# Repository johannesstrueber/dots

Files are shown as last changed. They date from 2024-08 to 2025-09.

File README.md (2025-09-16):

## Overview

DOTS is a compact, 6-channel Eurorack module designed for generating triggers and gates. This open hardware project allows you to build the module yourself, with instructions and resources provided. Please visit the [website](http://www.d-o-t-s.net) for more info.
<p align="left">
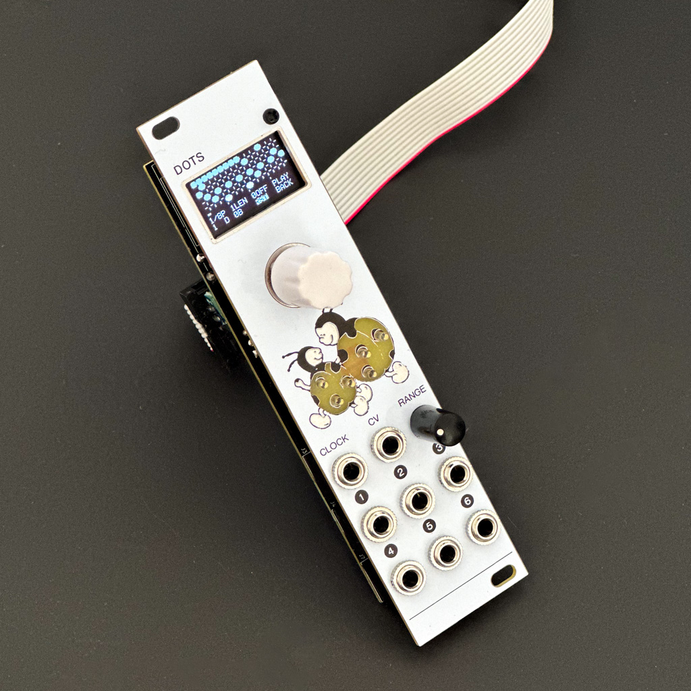
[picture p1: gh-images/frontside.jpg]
frontside
  
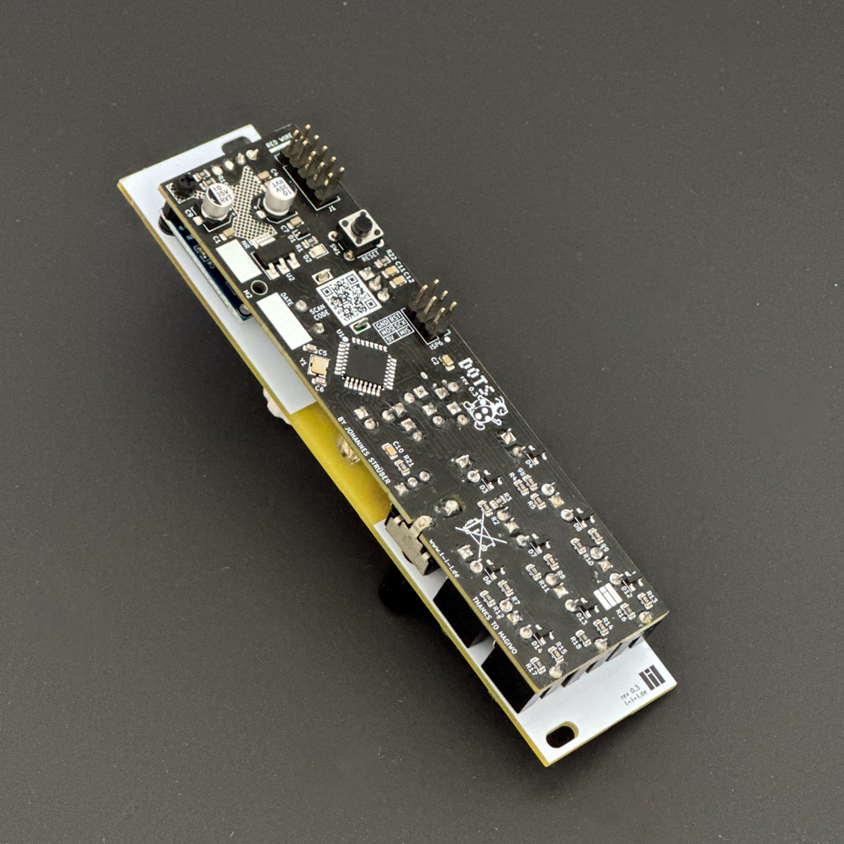
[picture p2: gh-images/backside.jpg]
backside
  
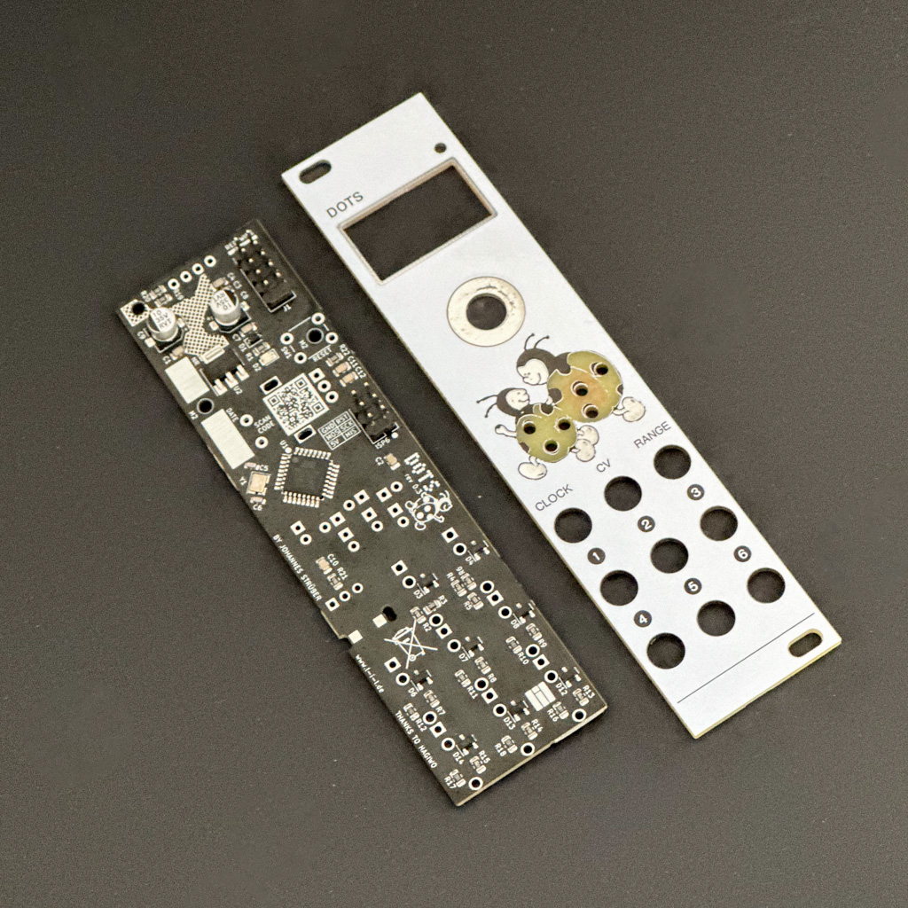
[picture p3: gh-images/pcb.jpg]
pcb
  
</p>

## Features

Watch a quick demo video [here](https://www.youtube.com/watch?v=c7fAQ9qpfXI).

- **6-Channel Trigger/Gate**: Generate triggers and gates for your modular system.
- **Compact Size**: Only 6hp wide, making it a handy addition to your setup.
- **Sync Capabilities**: Includes a clock and reset input, allowing it to function as a master or slave.
- **Visual Feedback**: Equipped with a screen and an UI.
- **Multiple Programs**: The firmware features multiple programs for different trigger/gate patterns and functionalities.

## Instructions

Check the [website](http://www.d-o-t-s.net) for detailed instructions on how to order, build and flash the module.

## Resources

- **[Website](http://www.d-o-t-s.net)**: Main website for the project.
- **[Order Guide](http://www.d-o-t-s.net/order)**: Order your DOTS PCB and front panel.
- **[Build Guide](http://www.d-o-t-s.net/build)**: Detailed instructions and an interactive Bill of Materials.
- **[Installation Guide](http://www.d-o-t-s.net/installation)**: Instructions for flashing the firmware to your DOTS module.
- **[Manual](http://www.d-o-t-s.net/manual)**: Comprehensive manual for using the module.
- **[Firmware on GitHub](https://www.github.com/releases)**: Download the latest firmware for the module.
- **[Modulargrid.net](https://modulargrid.net/e/other-unknown-dots)**: Module page on Modulargrid.net.

## Technical Specifications

- **Width**: 6HP
- **Depth**: ~30mm
- **Clock Input**: 0-5V triggers/gates
- **Reset Input**: 0-5V triggers/gates  
- **Outputs**: 6x 0-5V triggers/gates
- **Display**: 128x64 OLED
- **Microcontroller**: ATmega328P
- **Memory**: EEPROM storage for patterns and settings

### Modes

- **Step Sequencer**: Classic 16-step pattern programming with 8 pattern banks and visual step editing
- **Euclidean Sequencer**: Generate complex polyrhythmic patterns using Euclidean algorithms with individual channel control
- **Clock Divider**: Individual channel dividers (÷1 to ÷16) for creating polyrhythmic sequences and musical divisions
- **Random Trigger**: Probability-based trigger generation with adjustable chance per channel
- **Configuration Menu**: Comprehensive settings for BPM, clock modes, output types, and more

## Development

### Building from Source

1. **Prerequisites**: Install [PlatformIO](https://platformio.org) and [Git](https://git-scm.com)
2. **Clone**: `git clone https://github.com/johannesstrueber/dots.git`
3. **Build**: `platformio run`
4. **Flash**: Use `./flash_sequencer.sh` for automated flashing with default patterns

### Editing EEPROM Configuration

eeprom_config.cpp contains default settings and pattern configurations. Modify this file to customize the initial state of your module.

## Repository Structure

- **/code/include**: Header files and module implementations
- **/code/src/main.cpp**: Main firmware entry point
- **/code/src/eeprom_config.cpp**: Default settings and pattern configuration
- **/kicad_frontpanel**: Front panel PCB design files ([KiCad](https://kicad.org))
- **/kicad_main**: Main PCB design files ([KiCad](https://kicad.org))
- **diagram.json**: Hardware simulation ([WOKWI](https://wokwi.com))
- **platformio.ini**: Build configuration ([PlatformIO](https://platformio.org))
- **flash_module.sh**: Automated flashing script with EEPROM configuration

## Disclaimer

This is a personal project and not a commercial product. The creator is not liable for any damage caused by the module. Use at your own risk. The project is licensed under a [Creative Commons Attribution-NonCommercial-ShareAlike 4.0 International License][cc-by-nc-sa].

[][cc-by-nc-sa]

If you have any questions, feel free to contact the creator. This is a hobby project, and the creator is a web developer, not a professional hardware embedded systems builder; some hardware design or code decisions may seem unconventional.

Special thanks to HAGIWO for providing foundational knowledge.

Happy Building!

[cc-by-nc-sa]: http://creativecommons.org/licenses/by-nc-sa/4.0/
[cc-by-nc-sa-shield]: https://img.shields.io/badge/License-CC%20BY--NC--SA%204.0-lightgrey.svg

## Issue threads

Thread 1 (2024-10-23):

Feature request: Quick change in SEQ

Elko-cmd, 2024-10-23:
# Useability

## Hold and Twist
I would like to suggest registering a button hold of the encoder.
This could be used in the seq-program to invert the state of the individual Steps.
It would allow for a quicker change of patterns.
## Double press
A short double press of the Encoder could be used for quick access Play/Pause functionality

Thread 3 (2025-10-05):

PCB slot for RANGE potentiometer needs adjustment

johannesstrueber, 2025-10-05:
A user reported that the RANGE potentiometer did not sit straight because the slots in the PCB for the potentiometer legs are about 1mm too high. They resolved the issue by filing the PCB to extend the slot lower, after ensuring no PCB traces would be damaged.

**Suggested improvement:**
- Adjust the slot position for the RANGE potentiometer in the PCB design files so that it aligns properly and does not require manual modification by the user.
- Verify that moving the slot lower will not interfere with existing PCB traces.

**Reference:**
User feedback via email: "The RANGE potentiometer didn't sit straight. The slots in the PCB for the potentiometer legs are about 1mm too high. So, I filed the PCB to extend the slot lower. (I first checked that I wasn't damaging any PCB traces.)"

This will improve the assembly experience and reduce manual intervention.

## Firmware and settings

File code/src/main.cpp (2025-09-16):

#include "constants/ConstantsProgMem.h"
#include "utilities/Bit.h"
#include "utilities/SplashScreen.h"
#include "utilities/Startup.h"

#include <Adafruit_GFX.h>
#include <Adafruit_SSD1306.h>
#include <Arduino.h>
#include <EEPROM.h>
#include <Encoder.h>
#include <Wire.h>
#include <avr/pgmspace.h>

const uint8_t outputPins[] = {5, 6, 7, 8, 9, 10};
int8_t numChannels = 6;

bool clockIn = false;
bool oldClockIn = false;
bool resetIn = false;
bool oldResetIn = false;

Encoder Enc(3, 2);
int8_t enc = 0;
bool encLock = false;

const uint8_t rows = 6;
const uint8_t cols = 16;
const uint8_t pages = 8;
const uint8_t barLength = 4;

const uint8_t seqMatrixSize = pages * rows * cols / 8;
byte seqMatrix[seqMatrixSize];

uint8_t randomChannelValues[6] = {0, 0, 0, 0, 0, 0};

uint8_t seqCurrentPage = 1;
uint8_t seqCurrentLength = 1;
uint8_t seqCurrentOffset = 0;
uint8_t resetMode = 0;

uint8_t page = 0;
uint8_t bootMode = 0;

bool isPause = false;
uint8_t bpm;
uint16_t beatAtMs[4] = {0, 0, 0, 0};

bool clkMode = true;
bool outMode = true;
uint8_t intClock = 120;

uint8_t stepCount = 0;

Adafruit_SSD1306 display(128, 64, &Wire, -1);

uint8_t ranMode = 0;
uint8_t ranActiveChannels = 6;

enum MainPages { MAIN_MENU, SEQUENCER, EUCLIDEAN_SEQUENCER, RANDOM_TRIGGER, CLOCK_DIVIDER, CONFIG, INSTRUCTIONS };

int8_t newPosition = 2;
int8_t oldPosition = -2;

bool updateScreen = true;
bool updateTrigger = true;
bool needsThrottledUpdate = false;
bool button = false;
bool oldButton = false;
bool buttonOn = false;

int16_t potIn = 0;
int8_t randomValuePotIn = 0;
int8_t msDelay = 0;

unsigned long lastScreenUpdate = 0;
const unsigned long SCREEN_UPDATE_INTERVAL = 200;

unsigned long lastInternalClockStep = 0;

#include "ClockDivider.h"
#include "ConfigMenu.h"
#include "EuclideanSequencer.h"
#include "Instructions.h"
#include "MainMenu.h"
#include "RandomTrigger.h"
#include "StepSequencer.h"
#include "utilities/HandleReset.h"

void setup() {
    pinMode(A0, INPUT);       // POT
    pinMode(4, INPUT_PULLUP); // BUTTON
    pinMode(5, OUTPUT);       // CH1
    pinMode(6, OUTPUT);       // CH2
    pinMode(7, OUTPUT);       // CH3
    pinMode(8, OUTPUT);       // CH4
    pinMode(9, OUTPUT);       // CH5
    pinMode(10, OUTPUT);      // CH6

    EEPROM.begin();

    // config settings
    clkMode = EEPROM.read(390);
    intClock = EEPROM.read(391);
    bootMode = EEPROM.read(392);
    outMode = EEPROM.read(393);
    resetMode = EEPROM.read(387);

    // program settings
    loadStepSequencerSettings();
    loadRandomTriggerSettings();
    loadEuclideanSettings();
    loadChannelDividers();

    if (seqCurrentPage > pages)
        seqCurrentPage = 1;
    if (seqCurrentLength > pages)
        seqCurrentLength = 1;
    if (seqCurrentOffset > pages)
        seqCurrentOffset = 0;
    if (resetMode > 5)
        resetMode = 0;
    if (intClock > 200)
        intClock = 80;
    if (bootMode > 4)
        bootMode = 0;
    if (ranMode > 1)
        ranMode = 0;
    if (ranActiveChannels > 6)
        ranActiveChannels = 6;

    // euclidean sequencer
    if (eucPatternLength < 1 || eucPatternLength > 32)
        eucPatternLength = 16;

    for (int i = 0; i < 6; i++) {
        if (eucTracks[i].steps < 1 || eucTracks[i].steps > 32)
            eucTracks[i].steps = 16;
        if (eucTracks[i].hits > eucTracks[i].steps)
            eucTracks[i].hits = eucTracks[i].steps / 2;
        if (eucTracks[i].rotation >= eucTracks[i].steps)
            eucTracks[i].rotation = 0;
    }
    if (ranActiveChannels < 1)
        ranActiveChannels = 1;

    page = bootMode;

    display.begin(SSD1306_SWITCHCAPVCC, 0x3C);
    splashScreen();
    startupBlink();

    updateEuclideanPatterns();
}

void loop() {
    oldClockIn = clockIn;
    clockIn = digitalRead(12);
    oldResetIn = resetIn;
    resetIn = digitalRead(11);
    oldButton = button;
    button = 1 - digitalRead(4);
    newPosition = Enc.read();

    if (outMode || isPause)
        TriggerUtils::setAllOutputsLow();

    if (!oldButton && button) {
        buttonOn = true;
        updateScreen = true;
    } else
        buttonOn = false;

    if (!isPause && page != 0) {
        if (!oldClockIn && clockIn && !clkMode) {
            beatAtMs[3] = beatAtMs[2];
            beatAtMs[2] = beatAtMs[1];
            beatAtMs[1] = beatAtMs[0];
            beatAtMs[0] = millis();
            bpm = 45000 / (beatAtMs[0] - beatAtMs[3]);
            stepCount++;
            updateScreen = true;
            updateTrigger = true;
        }

        else if (clkMode) {
            unsigned long currentTime = millis();
            unsigned long stepInterval = 15000 / intClock;

            if (currentTime - lastInternalClockStep >= stepInterval) {
                stepCount++;
                updateScreen = true;
                updateTrigger = true;
                lastInternalClockStep = currentTime;
            }
        }
        potIn = analogRead(A0);
        randomValuePotIn = random(-100, 100);
        uint8_t delayPercent = map(potIn, 0, 1023, 0, 100);
        msDelay = round(randomValuePotIn * delayPercent / 100 * 15 / (clkMode ? intClock : bpm));
    }

    if (newPosition + 2 < oldPosition) {
        oldPosition = newPosition;
        if (!encLock)
            enc--;
        if (isPause || (page != SEQUENCER && page != EUCLIDEAN_SEQUENCER))
            updateScreen = true;
        else
            needsThrottledUpdate = true;

        if (!clkMode)
            updateTrigger = false;
    } else if (newPosition - 2 > oldPosition) {
        oldPosition = newPosition;
        if (!encLock)
            enc++;
        if (isPause || (page != SEQUENCER && page != EUCLIDEAN_SEQUENCER))
            updateScreen = true;
        else
            needsThrottledUpdate = true;

        if (!clkMode)
            updateTrigger = false;
    }

    handleReset();

    if (needsThrottledUpdate && (millis() - lastScreenUpdate >= SCREEN_UPDATE_INTERVAL)) {
        updateScreen = true;
        needsThrottledUpdate = false;
        lastScreenUpdate = millis();
    }

    if (updateScreen) {
        lastScreenUpdate = millis();
        switch (page) {
            case MAIN_MENU:
                mainMenuLoop();
                break;
            case SEQUENCER:
                sequencerLoop();
                break;
            case EUCLIDEAN_SEQUENCER:
                euclideanLoop();
                break;
            case RANDOM_TRIGGER:
                randomLoop();
                break;
            case CLOCK_DIVIDER:
                clockDividerLoop();
                break;
            case CONFIG:
                configMenuLoop();
                break;
            case INSTRUCTIONS:
                instructionsLoop();
                break;
        }
    }
}

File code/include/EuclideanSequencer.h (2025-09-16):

#ifndef EUCLIDEAN_SEQUENCER_H
#define EUCLIDEAN_SEQUENCER_H

#include <Adafruit_GFX.h>
#include <Adafruit_SSD1306.h>
#include <Arduino.h>
#include <EEPROM.h>
#include <Encoder.h>
#include <Wire.h>

#include "utilities/Display.h"
#include "utilities/Encoder.h"
#include "utilities/MenuLayout.h"
#include "utilities/PatternMath.h"
#include "utilities/Trigger.h"

extern Adafruit_SSD1306 display;
extern Encoder Enc;
extern int8_t enc;
extern bool updateScreen;
extern bool updateTrigger;
extern bool buttonOn;
extern uint8_t stepCount;
extern uint8_t page;
extern bool isPause;
extern const uint8_t outputPins[];
extern int8_t numChannels;
extern int16_t potIn;
extern int8_t msDelay;

struct EuclideanTrack {
    uint8_t steps;
    uint8_t hits;
    uint8_t rotation;
    bool mute;
    uint32_t pattern;
};

extern const char channelIndexText[];
extern const char stepIndexText[];
extern const char lengthIndexText[];
extern const char backText[];
extern const char playText[];
extern const char pauseText[];

extern const char eucHitsText[];
extern const char eucRotationText[];
extern const char eucMuteText[];
extern const char eucLiveText[];

extern const char *const resetOptions[];
extern uint8_t resetMode;

char eucBuffer[5];

EuclideanTrack eucTracks[6] = {{16, 4, 0, false, 0}, {16, 3, 0, false, 0}, {12, 5, 0, false, 0}, {8, 3, 0, false, 0}, {16, 7, 0, false, 0}, {16, 2, 0, false, 0}};

uint8_t eucCurrentTrack = 0;
uint8_t eucPatternLength = 16;
uint8_t eucCurrentStep = 0;

enum EuclideanEncoderOptions {
    EUC_ENC_CHANNEL_1 = 1,
    EUC_ENC_CHANNEL_2,
    EUC_ENC_CHANNEL_3,
    EUC_ENC_CHANNEL_4,
    EUC_ENC_CHANNEL_5,
    EUC_ENC_CHANNEL_6,
    EUC_ENC_LENGTH,
    EUC_ENC_STEPS,
    EUC_ENC_HITS,
    EUC_ENC_ROTATION,
    EUC_ENC_MUTE,
    EUC_ENC_RESET,
    EUC_ENC_BACK
};

uint32_t generateEuclideanPattern(uint8_t steps, uint8_t hits) {
    return PatternMath::generateEuclideanPattern(steps, hits);
}

uint32_t rotatePattern(uint32_t pattern, uint8_t steps, uint8_t rotation) {
    return PatternMath::rotatePattern(pattern, steps, rotation);
}

void updateEuclideanPatterns() {
    for (int i = 0; i < 6; i++) {
        uint32_t basePattern = generateEuclideanPattern(eucTracks[i].steps, eucTracks[i].hits);
        eucTracks[i].pattern = rotatePattern(basePattern, eucTracks[i].steps, eucTracks[i].rotation);
    }
}

bool isEuclideanStepActive(uint8_t track, uint8_t step) {
    if (track >= 6)
        return false;
    if (step >= eucTracks[track].steps)
        return false;
    return PatternMath::isStepActive(eucTracks[track].pattern, step);
}

void drawPolygon(uint8_t centerX, uint8_t centerY, uint8_t radius, uint8_t steps, uint8_t currentStep, uint32_t pattern) {
    if (steps == 1) {

        display.fillCircle(centerX, centerY, 3, WHITE);
        return;
    } else if (steps == 2) {

        display.drawLine(centerX - 5, centerY, centerX + 5, centerY, WHITE);

        bool isActive1 = (pattern >> 0) & 1;
        bool isActive2 = (pattern >> 1) & 1;
        bool isCurrent1 = (0 == currentStep);
        bool isCurrent2 = (1 == currentStep);

        if (isCurrent1) {
            display.fillCircle(centerX - 5, centerY, 2, WHITE);
            if (!isActive1)
                display.fillCircle(centerX - 5, centerY, 1, BLACK);
        } else if (isActive1) {
            display.fillCircle(centerX - 5, centerY, 1, WHITE);
        }

        if (isCurrent2) {
            display.fillCircle(centerX + 5, centerY, 2, WHITE);
            if (!isActive2)
                display.fillCircle(centerX + 5, centerY, 1, BLACK);
        } else if (isActive2) {
            display.fillCircle(centerX + 5, centerY, 1, WHITE);
        }
        return;
    }

    if (steps < 3)
        steps = 3;
    if (steps > 16)
        steps = 16;

    for (int i = 0; i < steps; i++) {
        float angle1 = (2.0 * PI * i) / steps - PI / 2;
        float angle2 = (2.0 * PI * (i + 1)) / steps - PI / 2;

        int x1 = centerX + radius * cos(angle1);
        int y1 = centerY + radius * sin(angle1);
        int x2 = centerX + radius * cos(angle2);
        int y2 = centerY + radius * sin(angle2);

        display.drawLine(x1, y1, x2, y2, WHITE);
    }

    for (int i = 0; i < steps; i++) {
        float angle = (2.0 * PI * i) / steps - PI / 2;
        int x = centerX + radius * cos(angle);
        int y = centerY + radius * sin(angle);

        bool isActive = (pattern >> i) & 1;
        bool isCurrent = (i == currentStep);

        if (isCurrent) {
            display.fillCircle(x, y, 3, WHITE);
            if (isActive) {
                display.fillCircle(x, y, 2, BLACK);
                display.fillCircle(x, y, 1, WHITE);
            } else {
                display.fillCircle(x, y, 1, BLACK);
            }
        } else if (isActive) {
            display.fillCircle(x, y, 2, WHITE);
        } else {
            display.drawCircle(x, y, 1, WHITE);
        }
    }
}
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

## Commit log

2024-08-30 version bump
    [kicad_frontpanel.kicad_pcb]
2024-09-15 pcb silkscreen rev bump
    [kicad_frontpanel.kicad_pcb]
2024-09-15 add missing potentiometer bom value
    [peripheral.kicad_sch]
2025-09-07 feat: features, fixes and refactor
    [ClockDivider.h, EuclideanSequencer.h]
2025-09-10 improvements and fixes to programs
    [ClockDivider.h, EuclideanSequencer.h, StepSequencer.h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]
2025-09-14 fix: step sequencer page length and offset handling
    [StepSequencer.h]
2025-09-14 fix: euclidean sequencer ignore isPause to always start
    [EuclideanSequencer.h]
2025-09-14 fix: no invisible channels in ui auto jump enc pos
    [RandomTrigger.h]
2025-09-16 fix rotation value and limit step value to max pattern length
    [EuclideanSequencer.h]

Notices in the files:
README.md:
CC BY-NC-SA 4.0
